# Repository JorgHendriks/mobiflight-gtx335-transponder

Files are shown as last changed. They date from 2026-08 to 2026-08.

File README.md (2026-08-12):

# GTX 335 Flight-Simulator Transponder

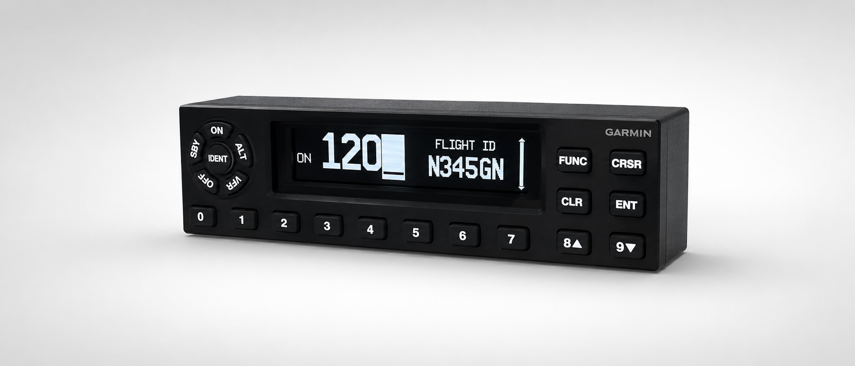
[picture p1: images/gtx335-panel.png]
GTX 335 flight-simulator transponder


A DIY desktop flight-simulator transponder inspired by the Garmin GTX 335 and designed for use with [MobiFlight](https://www.mobiflight.com/). The project combines a custom PCB, a 3D-printed and laser-engraved enclosure, and MobiFlight community firmware.

> [!IMPORTANT]
> This is an unofficial hobby project for flight simulation. It is not a real transponder, does not transmit ADS-B or radio signals, is not certified for aviation use, and is not affiliated with or endorsed by Garmin.

## Features

- Raspberry Pi Pico-based board with a 3.12-inch OLED and 20 illuminated buttons
- Most functions of the real GTX 335 are implemented, including transponder, altitude, and timer functions
- Preconfigured MobiFlight firmware and an example Microsoft Flight Simulator 2024 project

## Repository contents

| Folder | Contents |
|---|---|
| [`pcb`](pcb/README.md) | KiCad source, schematic, bill of materials, component notes, and ready-to-order fabrication archive |
| [`mechanical`](mechanical/README.md) | FreeCAD source, printable parts, laser artwork, print settings, and enclosure assembly notes |
| [`firmware`](firmware/README.md) | MobiFlight community firmware source and build instructions |
| [`firmware/MF_Configs`](firmware/MF_Configs) | Board configuration backup and an example MSFS 2024 MobiFlight project |

## What you need

- The components listed in the [PCB bill of materials](pcb/README.md#bill-of-materials)
- A manufactured and assembled PCB
- The hardware, printed enclosure parts and engraved controls described in the [enclosure guide](mechanical/README.md)
- A Windows PC running [MobiFlight](https://www.mobiflight.com/)
- Microsoft Flight Simulator 2024 if you want to use the included example project

## Quick start

### 1. Build the hardware

Order and assemble the board by following the [PCB guide](pcb/README.md), then print, engrave, and assemble the controls and enclosure by following the [mechanical guide](mechanical/README.md).

Pay particular attention to the OLED configuration and LED polarity of the switches.

### 2. Install the community firmware package

1. Download `GTX335_<version>.zip` from the [latest GitHub release](../../releases/latest).
2. Extract the archive into:

   ```text
   %LocalAppData%\MobiFlight\MobiFlight Connector\Community
   ```

   The resulting directory should be `Community\GTX335`.
3. Restart MobiFlight.
4. Connect the panel over USB and open **Extras > Settings > MobiFlight Modules**.
5. If necessary, reset the Pico from its board context menu. Then choose **Update firmware > Community > JH GTX335**.

The custom device and its twenty named buttons are stored in the firmware configuration, so a manual pin-by-pin setup is not normally required. For screenshots and more detail, see MobiFlight's [Community Board and Custom Devices user guide](https://github.com/MobiFlight/MobiFlight-Connector/wiki/User-guide-%E2%80%90-Community-Board-and-Custom-Devices).

If preferred, build a package from source by following the [firmware build instructions](firmware/README.md).

### 3. Load the MSFS 2024 example project

1. In MobiFlight 11 or newer, open [`firmware/MF_Configs/GTX335_MSFS2024.mfproj`](firmware/MF_Configs/GTX335_MSFS2024.mfproj), or merge its profile into an existing project.
2. If MobiFlight reports a missing controller, use **Extras > Controller Bindings** to bind the profile to the connected `JH GTX335`.
3. Start Microsoft Flight Simulator 2024, load an aircraft, and click **Run** in MobiFlight.

See the MobiFlight documentation for [opening and merging projects](https://docs.mobiflight.com/features/projects/) and [updating controller bindings](https://docs.mobiflight.com/features/controller-bindings/).

The included profile targets the generic MSFS 2024 transponder variables and events. Aircraft with custom avionics may need their own MobiFlight presets or calculator-code mappings.

## Current limitations

- Flight ID is display-only and cannot be entered from the panel.
- The SYS menu is only partially implemented.

## Building the firmware

Developer prerequisites, the PlatformIO command, generated files, and release-version handling are documented in [`firmware/README.md`](firmware/README.md).

## Licence

The firmware is available under the [MIT License](firmware/LICENSE). The PCB, 3D models, fabrication files, artwork, and project documentation are available for non-commercial use under [CC BY-NC-SA 4.0](LICENSE.md).

Third-party names and trademarks are not included in these licences. See the [complete licensing details](LICENSE.md).

## Contributing

Bug reports, tested aircraft mappings, firmware improvements, and fabrication feedback are welcome. When reporting a hardware problem, include the PCB revision, Pico and OLED variants, MobiFlight version, simulator and aircraft, and clear photos where relevant.

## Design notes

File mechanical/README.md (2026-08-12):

# Enclosure and controls

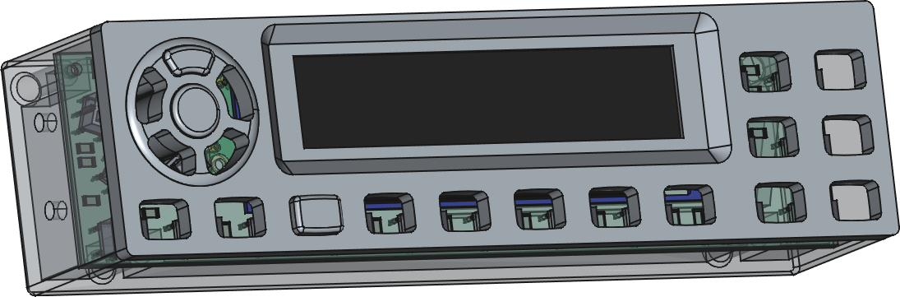
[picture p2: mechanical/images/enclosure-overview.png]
GTX 335 enclosure overview


## Hardware

- 4 × M2 x 15 mm + 3 mm Brass PCB standoff spacers
- 4 × M2 × 6 mm screws
- 4 x M3 x 8 mm screws
- Matte black paint

## 3D Printing

Use:

- White PLA for the buttons and faceplate
- Matte black PLA for the case

### Buttons

Print several spare buttons. They require little filament or paint, and achieving correct laser alignment may take more than one attempt.

Required quantities:

- `button_std`: print at least 2
- All other button models: print at least 1 each

Print the buttons with their top surfaces facing down on a smooth PEI build plate.

Recommended slicer settings:

| Setting | Value |
|---|---|
| Wall generator | Arachne |
| Initial layer flow ratio | 1.06 |
| Bottom surface pattern | Hilbert curve |
| Elephant foot compensation | 0.08 mm |

The Arachne wall generator is recommended because of the thin walls and small printed features.

### Faceplate

Recommended slicer settings:

| Setting | Value |
|---|---|
| Ironing | Enabled |
| Ironing flow | 23% |

## Laser Engraving

Use three separate laser sessions:

1. Faceplate
2. Standard buttons
3. Round and dome buttons

For each session:

1. Focus the laser on the top surface of the printed part.
2. Engrave the alignment outline onto the surface underneath.
3. Position the printed part inside the engraved outline.

Reference settings for a 10 W diode laser:

| Operation | Power | Speed | Focus |
|---|---:|---:|---|
| Standard raster engraving | 15% | 2800 mm/min | Focused |
| Button outline engraving | 50% | 2000 mm/min | Defocused |

## Assembly

Depending on the dimensional accuracy of your printer, the faceplate holes for the PCB standoff spacers may need to be prepared before final assembly.

Carefully form the threads using an M2 self-tapping screw before installing the PCB standoffs or final screws. Keep the screw perpendicular to the printed part and avoid overtightening.

## Mounting

The case includes two M4 side-mounting holes with 16 mm center-to-center spacing. The hole centers are positioned 12 mm from the rear of the case.

M4 side-mounting hole dimensions

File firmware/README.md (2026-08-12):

# GTX335 Firmware

This directory contains the configured MobiFlight community firmware for the GTX335 flight-simulator transponder. It targets the original RP2040-based Raspberry Pi Pico v1 and builds the `jh_gtx335` PlatformIO environment.

> **Disclaimer:** This firmware was created as an AI experiment, and its entire codebase was AI-generated; though it works, it does not meet the author's usual coding standards and should be reviewed accordingly.

End users normally install the precompiled community package from a GitHub release as described in the [project quick start](../README.md#quick-start). The instructions below are for developers building the firmware from source.

## Prerequisites

- [Git](https://git-scm.com/)
- [Visual Studio Code](https://code.visualstudio.com/) with the [PlatformIO IDE extension](https://platformio.org/install/ide?install=vscode), or the standalone [PlatformIO Core CLI](https://docs.platformio.org/en/latest/core/installation/index.html)
- Internet access for the first build

The first build downloads the pinned MobiFlight Firmware Source core and the required PlatformIO platforms and libraries. The downloaded `src`, `.pio`, `_build`, and `_dist` directories are generated locally and ignored by Git.

## Compile

Open the `firmware` directory—not the repository root—as the PlatformIO project. From a terminal in that directory, run:

```console
pio run -e jh_gtx335
```

In VS Code, the equivalent is **PlatformIO > Project Tasks > jh_gtx335 > General > Build**.

The build uses:

- MobiFlight Firmware Source core `3.0.0`
- Raspberry Pi Pico / RP2040 with the Arduino-Pico core
- U8g2 for the SSD1322 display

## Build artifacts

A successful local build with no explicit version produces:

```text
.pio/build/jh_gtx335/jh_gtx335_1_0_0.uf2
_dist/GTX335_1.0.0.zip
```

The UF2 file is the compiled firmware. The ZIP file is the complete MobiFlight community package and includes the board definition, custom-device definition, reset firmware, and compiled UF2 in the directory layout expected by MobiFlight.

The `_build` directory is an intermediate staging area.

## Set a build version

Set the `VERSION` environment variable before building to create versioned firmware and package filenames. In PowerShell:

```powershell
$env:VERSION = "1.0.0"
pio run -e jh_gtx335
```

On macOS or Linux:

```sh
VERSION=1.0.0 pio run -e jh_gtx335
```

GitHub release builds take the version from the release tag automatically. Prefer tags such as `v1.0.0`.

## Flash a development build

For normal use, install the generated community ZIP through MobiFlight as described in the [project quick start](../README.md#quick-start).

To flash the UF2 directly during development:

1. Disconnect the Pico.
2. Hold **BOOTSEL** while reconnecting its USB cable.
3. Release **BOOTSEL** when the `RPI-RP2` drive appears.
4. Copy the generated `.uf2` file to that drive.

The Pico restarts automatically after accepting the file. Direct UF2 flashing installs the firmware but does not install the board and device definitions into MobiFlight; use the generated community ZIP as well if MobiFlight has not already been configured for this board.

## Clean and rebuild

```console
pio run -e jh_gtx335 -t clean
pio run -e jh_gtx335
```

## Source layout

| Path | Purpose |
|---|---|
| `GTX335/GTX335State.*` | Panel state, key behavior, timers, message handling, and local settings |
| `GTX335/GTX335Renderer.*` | SSD1322 screen rendering and power/brightness control |
| `GTX335/GTX335Input.*` | Button polling, debouncing, long presses, and repeat behavior |
| `GTX335/GTX335Transport.*` | Named button events sent to MobiFlight |
| `GTX335/MFCustomDevice.*` | Integration with the MobiFlight custom-device API |
| `GTX335/Community` | Board, device, reset-firmware, and release-package metadata |
| `MF_Configs` | MobiFlight board backup and example MSFS 2024 project |

Hardware pin assignments are centralized in `GTX335/GTX335Pins.h`; the matching fixed MobiFlight configuration is in `GTX335/MFCustomDevicesConfig.h`.

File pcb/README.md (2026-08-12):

# PCB

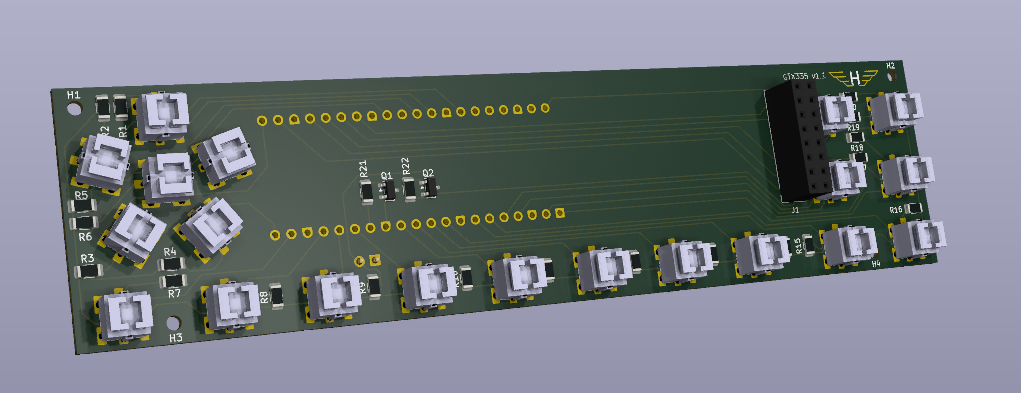
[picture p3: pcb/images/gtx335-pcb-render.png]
GTX335 PCB rendering


## PCB manufacturing

The fabrication files for the latest PCB are included in:

[Download the GTX335 v1.1 PCB fabrication files](./GTX335_v1_1_pcb_fab.zip)

Upload the ZIP archive directly to your PCB manufacturer and select a standard board thickness of **1.6 mm**.

## Schematic

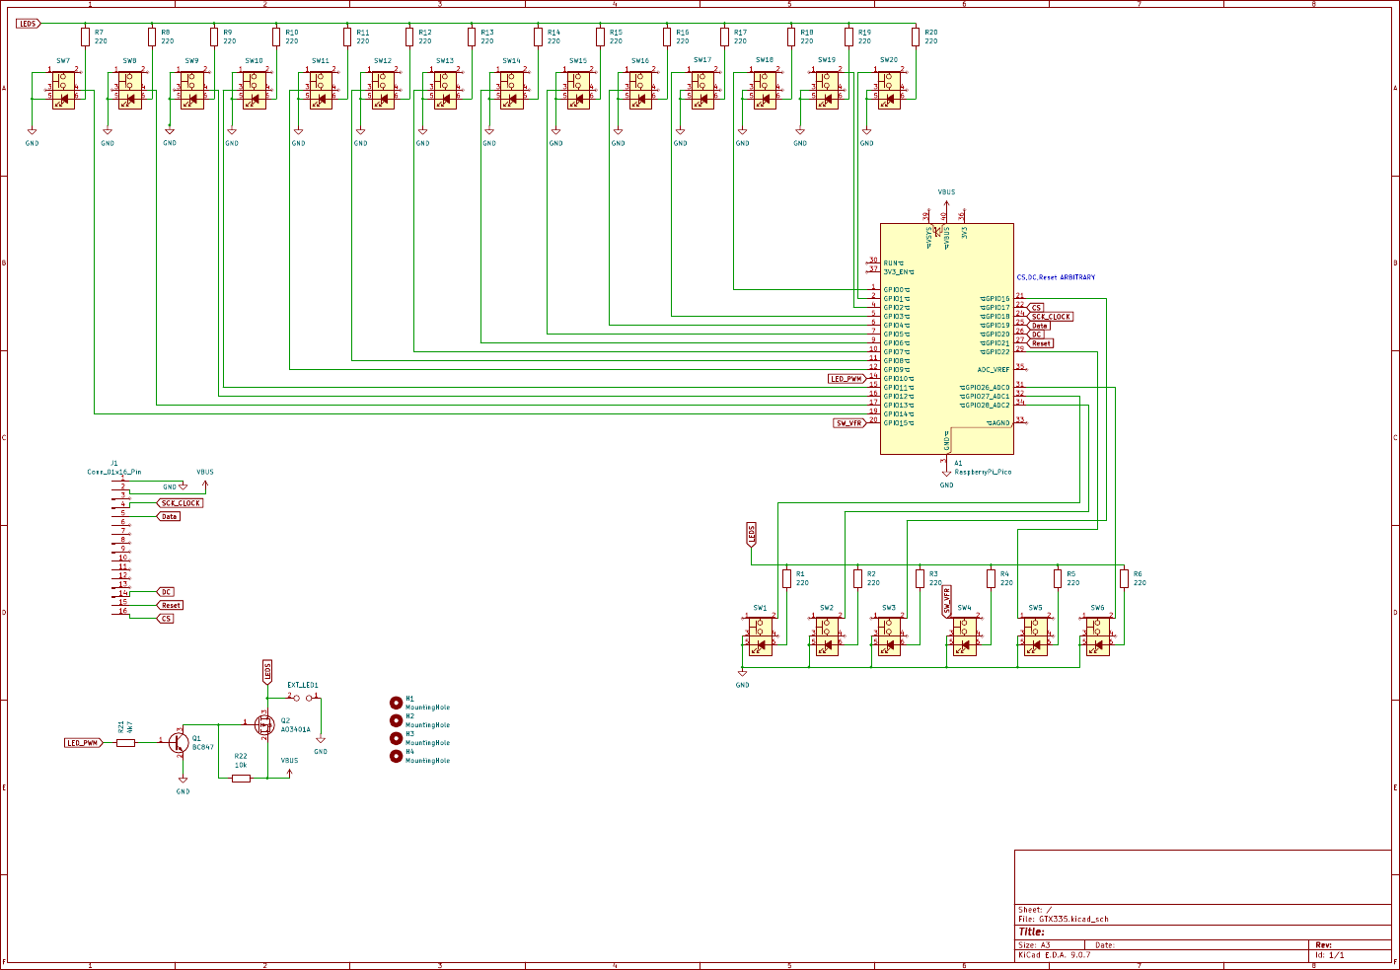
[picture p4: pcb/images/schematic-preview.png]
GTX335 PCB schematic


[View the full-resolution schematic](GTX335_Schematic.pdf)

## Bill of materials

| Designators | Quantity | Component | Specification |
|---|---:|---|---|
| SW1-SW20 | 20 | Illuminated tactile switch | 6 x 6 x 7.2 mm, six pins, white LED |
| R1-R20 | 20 | Resistor | 220 ohm, 1206 package |
| R21, R22 | 2 | Resistor | 10 kohm, 1206 package |
| Q1 | 1 | NPN transistor | BC847, SOT-23 package |
| Q2 | 1 | P-channel MOSFET | AO3401A, SOT-23 package |
| J1 | 1 | Socket header | 2 x 8 pins, 2.54 mm pitch, vertical |
| A1 | 2 | Female socket header | 20 pins, 2.54 mm pitch |
| - | 1 | Microcontroller board | Raspberry Pi Pico v1 |
| - | 1 | OLED display | 3.12-inch, 256 x 64 pixels, SSD1322 controller |

## Parts

### Illuminated tactile switches

Use twenty illuminated tactile switches with the following specifications:

- Body size: 6 x 6 mm
- Total height: 7.2 mm
- Number of pins: 6
- Integrated LED colour: white
- Switch contact: normally open

[6 x 6 x 7.2 mm illuminated tactile switch with white LED](https://nl.aliexpress.com/item/1005008121502218.html)

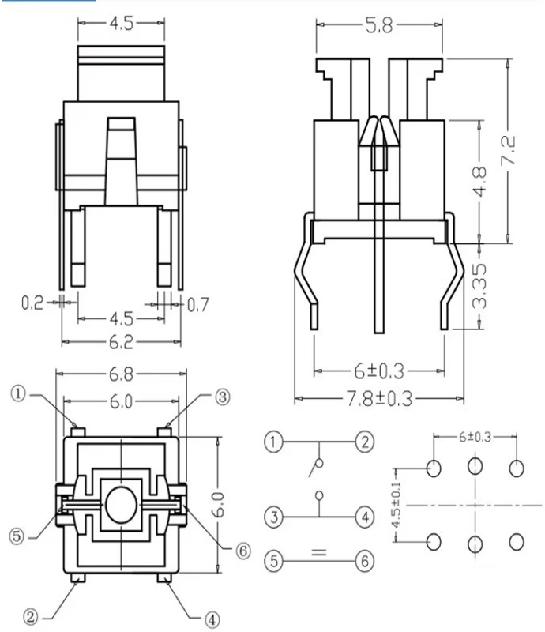
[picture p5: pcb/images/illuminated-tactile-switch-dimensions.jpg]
Illuminated tactile switch technical drawing


Four pins form the two duplicated switch contacts. The remaining two pins connect the integrated LED.

Verify the dimensions, height, and six-pin layout before ordering. Similar-looking 6 x 6 mm switches may use a different height, LED polarity, pin arrangement, or PCB footprint.

### OLED display

Use a 3.12-inch graphic OLED module with the following specifications:

- Resolution: 256 x 64 pixels
- Controller: SSD1322
- Interface: 4-wire SPI
- Connector: 16 pins
- Module width: approximately 100.5 mm
- Module height: approximately 33.5 mm

[SSD1322 3.12-inch 256 x 64 OLED display](https://nl.aliexpress.com/item/1005003091450549.html)

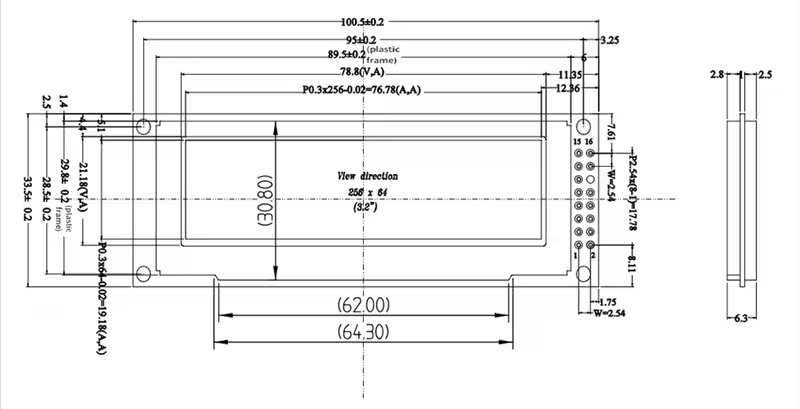
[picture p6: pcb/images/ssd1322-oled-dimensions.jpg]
SSD1322 OLED technical drawing


Check the specs carefully as some OLED screens are sold without the interface board or with different chipsets.

#### OLED pinout

| Pin | Symbol | Function | Use in 4-wire SPI mode |
|---:|---|---|---|
| 1 | VSS | Power-supply ground | Ground |
| 2 | VCC_IN | Positive power supply | Power |
| 3 | NC | Not connected | Not used |
| 4 | D0/CLK | Parallel data D0 / serial clock | SPI clock |
| 5 | D1/DIN | Parallel data D1 / serial data | SPI data |
| 6 | D2 | Parallel data D2 | Not used |
| 7 | D3 | Parallel data D3 | Not used |
| 8 | D4 | Parallel data D4 | Not used |
| 9 | D5 | Parallel data D5 | Not used |
| 10 | D6 | Parallel data D6 | Not used |
| 11 | D7 | Parallel data D7 | Not used |
| 12 | E/RD# | Enable / read | Not used after interface configuration |
| 13 | R/W# | Read / write | Not used after interface configuration |
| 14 | D/C# | Data / command selection | Data/command |
| 15 | RES# | Reset | Reset |
| 16 | CS# | Chip selection | Chip select |

### Raspberry Pi Pico

Use a **Raspberry Pi Pico v1** fitted with two 20-pin, 2.54 mm pitch headers.

The PCB is designed for the original RP2040-based Raspberry Pi Pico. Other Pico variants are not currently supported.

Install the Pico in the two corresponding 20-pin header rows on the PCB.

## Assembly notes

### Configure the OLED for 4-wire SPI

Before installing the OLED module, configure it for the **4-wire SPI interface**. This mode may be marked as **4SPI** on the display PCB.

Configure the interface-selection jumpers by soldering the required **0 ohm jumper resistors** according to the 4SPI configuration shown for the module.

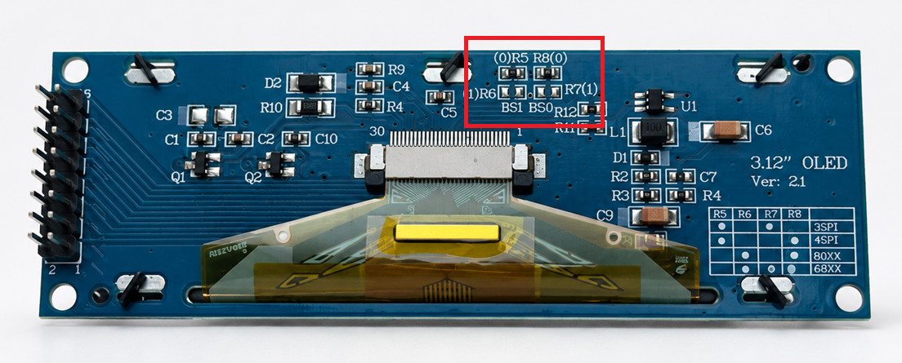
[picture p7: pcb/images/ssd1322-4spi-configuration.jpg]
OLED 4-wire SPI jumper configuration


### Install the illuminated tactile switches

Each tactile switch contains a polarity-sensitive LED.

The **small square PCB pad is ground** and must connect to the negative LED terminal (short).

To test the switch LEDs during assembly, apply 3–5 V DC to pin 2 of the EXT LED connector and connect the supply ground to any PCB ground point.

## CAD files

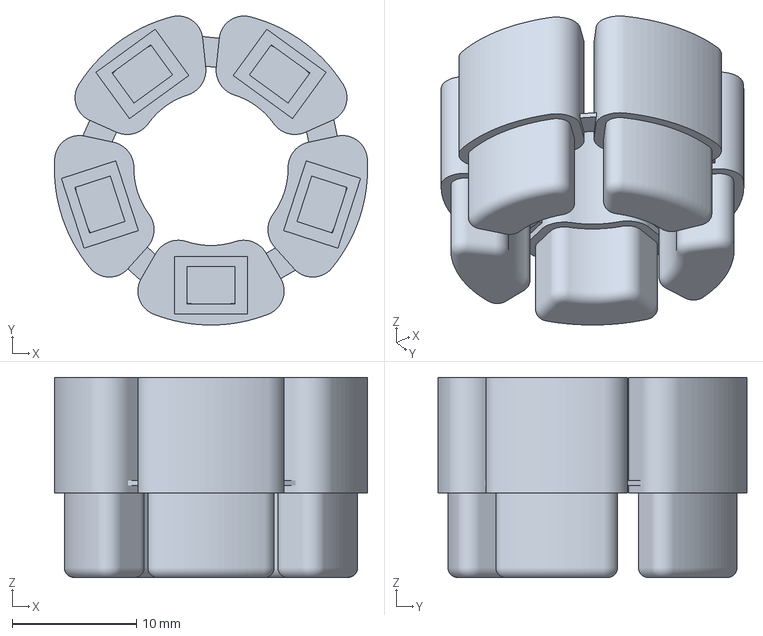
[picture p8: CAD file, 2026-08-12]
mechanical/Button_dome_print.3mf
25.2 x 24.9 x 16.1 mm

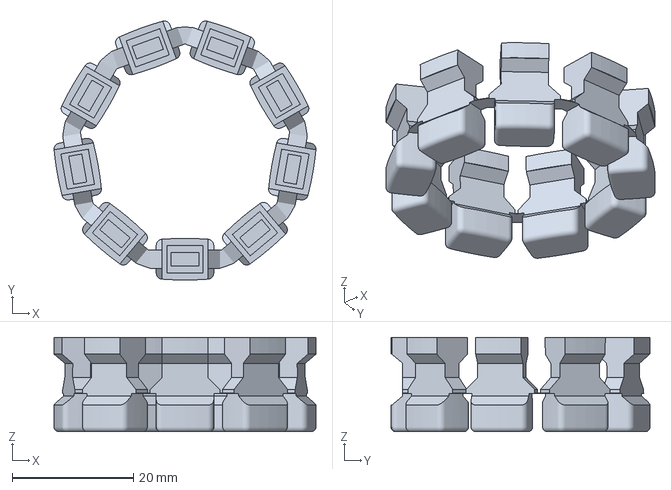
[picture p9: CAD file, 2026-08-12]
mechanical/Button_std_print.3mf
43.3 x 42.8 x 15.6 mm

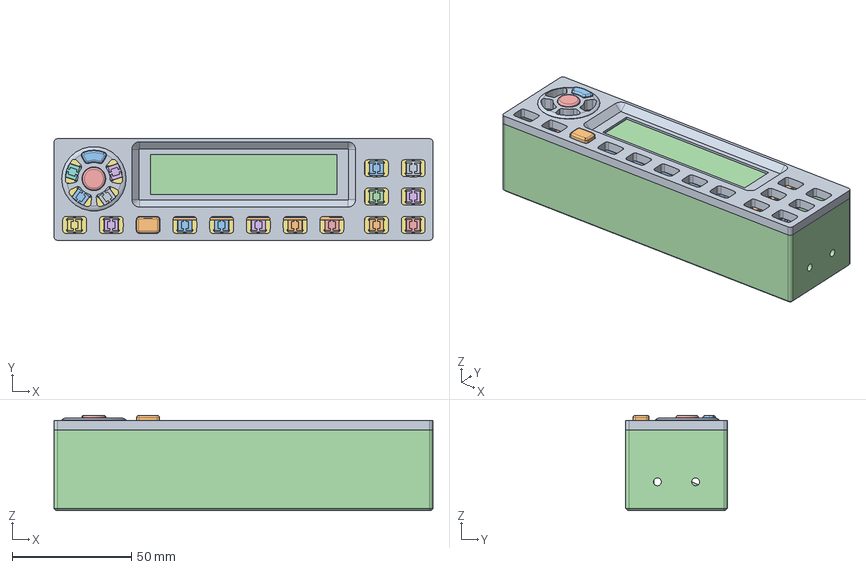
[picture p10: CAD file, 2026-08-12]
mechanical/GTX335.FCStd
158.8 x 42.6 x 39.8 mm
Faceplate
Button Standard
Button Dome
SW01 Switch Housing
SW01 Switch Base
SW02 Switch Housing
SW02 Switch Base
R01 1206 Resistor
R02 1206 Resistor
R03 1206 Resistor
SW03 Switch Housing
SW03 Switch Base
SW04 Switch Housing
SW04 Switch Base
R04 1206 Resistor
R05 1206 Resistor
SW05 Switch Housing
SW05 Switch Base
R06 1206 Resistor
R07 1206 Resistor
R08 1206 Resistor
SW06 Switch Housing
SW06 Switch Base
SW07 Switch Housing
SW07 Switch Base
SW08 Switch Housing
SW08 Switch Base
R09 1206 Resistor
R10 1206 Resistor
R11 1206 Resistor
SW09 Switch Housing
SW09 Switch Base
SW10 Switch Housing
SW10 Switch Base
SW11 Switch Housing
SW11 Switch Base
R12 1206 Resistor
SW12 Switch Housing
SW12 Switch Base
Q1 BC847
R13 1206 Resistor
R14 1206 Resistor
SW13 Switch Housing
SW13 Switch Base
2x08 Pin Socket
R15 1206 Resistor
SW14 Switch Housing
SW14 Switch Base
SW15 Switch Housing
SW15 Switch Base
R16 1206 Resistor
R17 1206 Resistor
Q2 AO3401A
SW16 Switch Housing
SW16 Switch Base
R18 1206 Resistor
R19 1206 Resistor
SW17 Switch Housing
SW17 Switch Base
R20 1206 Resistor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

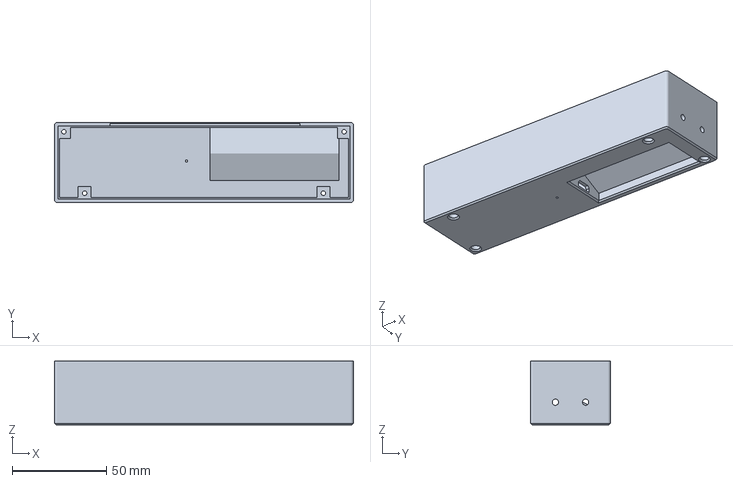
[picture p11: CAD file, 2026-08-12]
mechanical/GTX335_case.3mf
158.8 x 42.6 x 33.8 mm

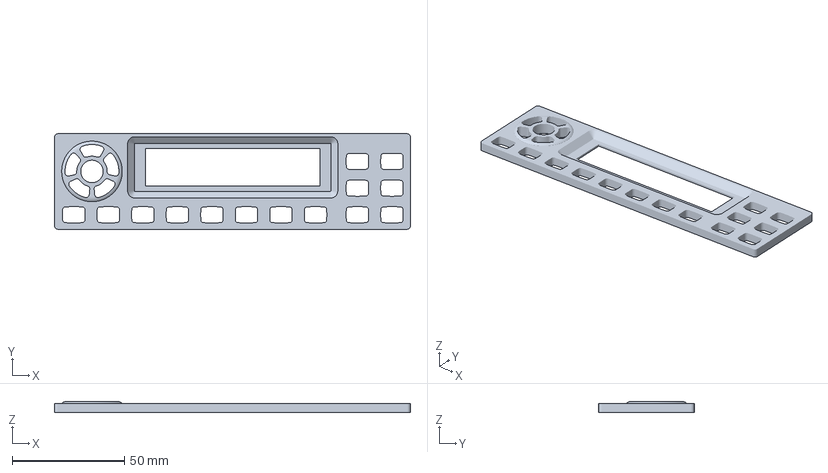
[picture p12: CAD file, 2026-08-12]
mechanical/GTX335_faceplate.3mf
158.8 x 42.6 x 5.00 mm

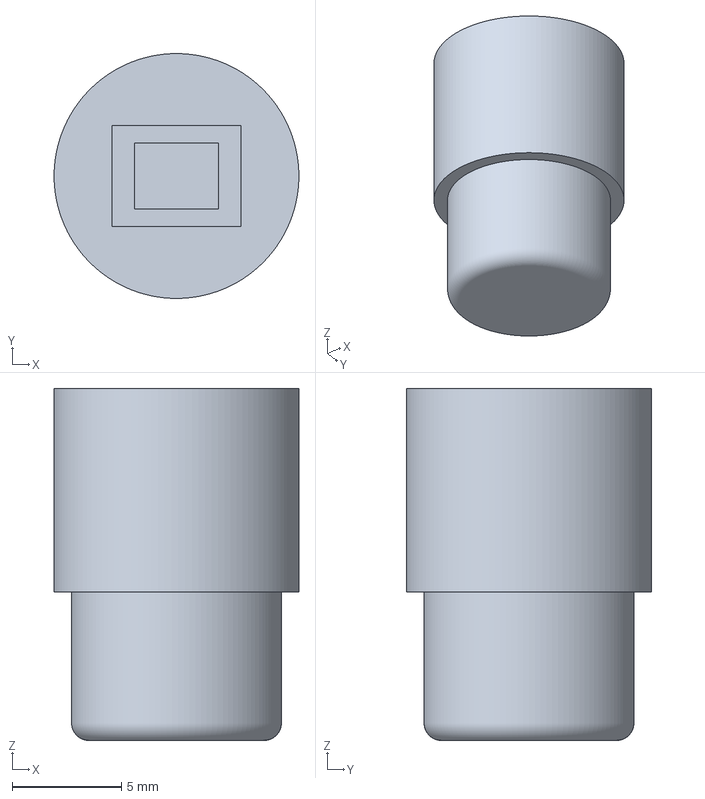
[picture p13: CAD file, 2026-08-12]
mechanical/Button_round.3mf
11.2 x 11.2 x 16.1 mm

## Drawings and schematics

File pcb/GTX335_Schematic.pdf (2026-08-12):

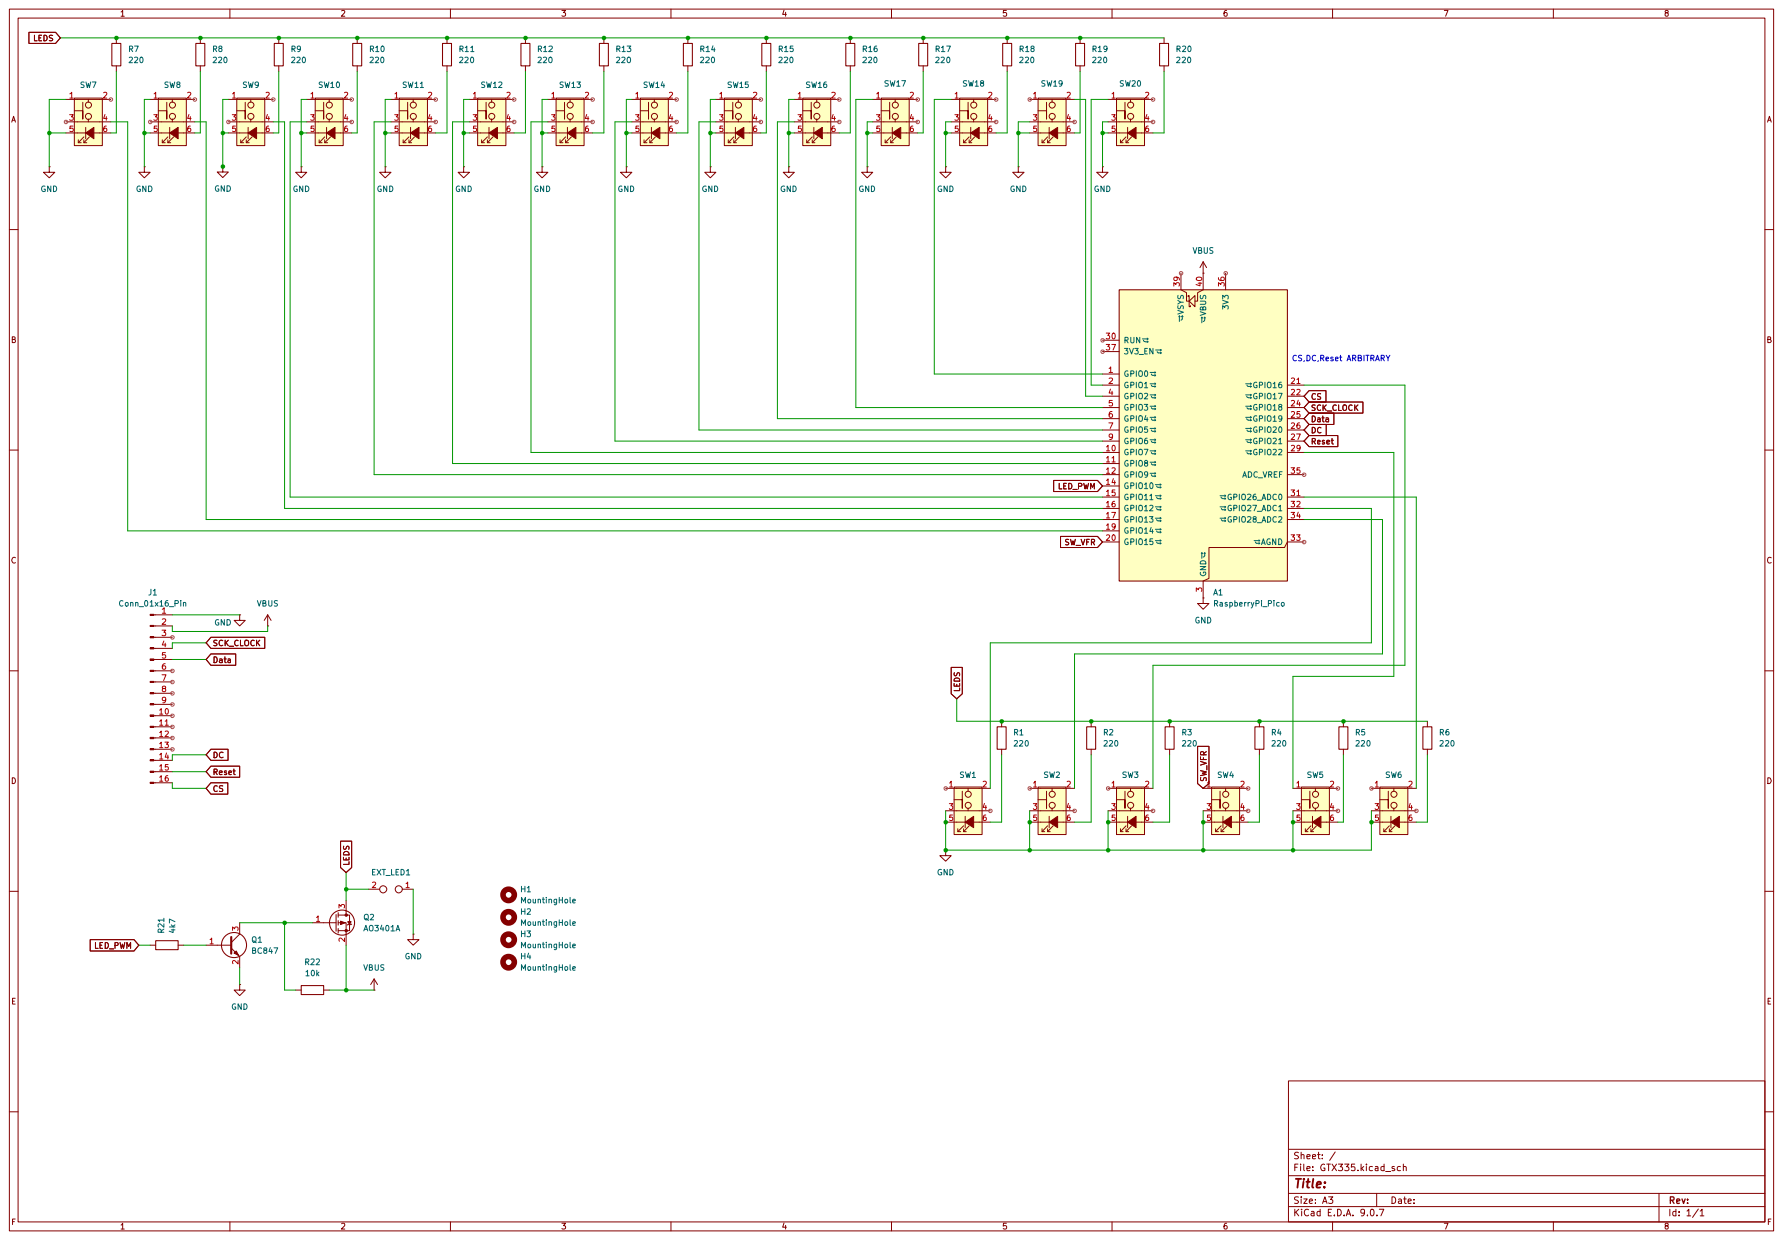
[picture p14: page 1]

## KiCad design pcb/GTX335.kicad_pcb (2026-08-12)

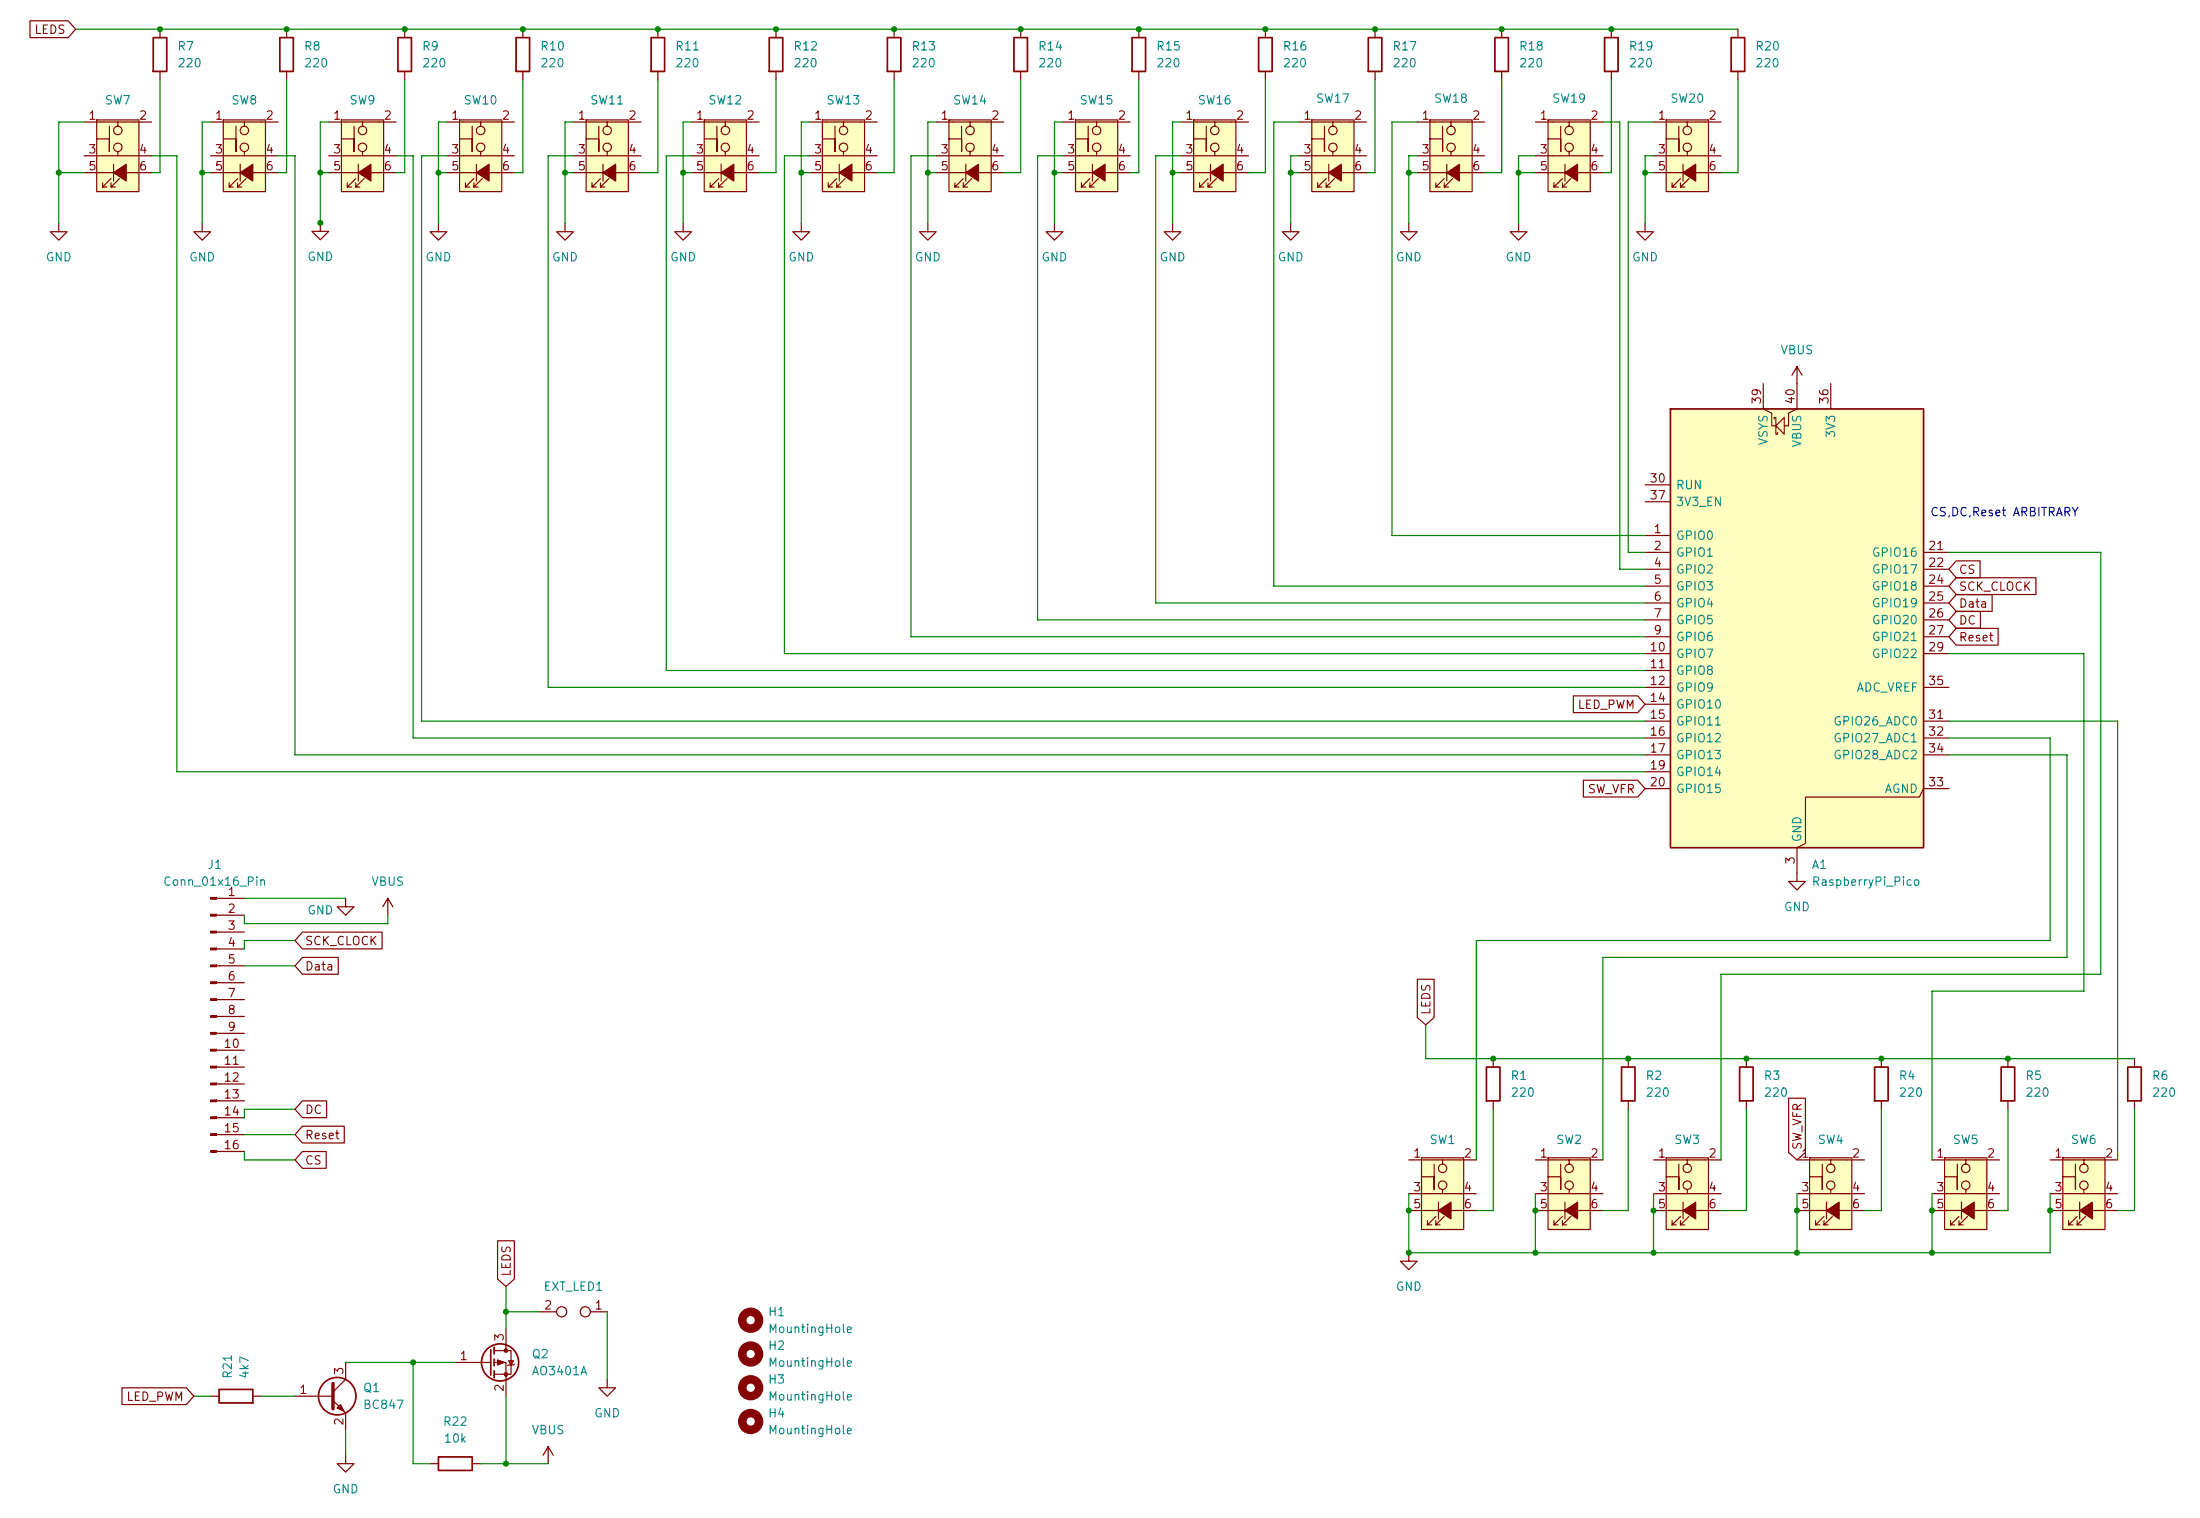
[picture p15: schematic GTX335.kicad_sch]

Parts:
A1: RaspberryPi_Pico; RaspberryPi_Pico_Common_Unspecified
EXT_LED1: TestPoint_2Pole; PinHeader_2x01_P2.54mm_Vertical
H1, H2, H3, H4: MountingHole; MountingHole_2.2mm_M2
J1: Conn_01x16_Pin; PinSocket_2x08_P2.54mm_Vertical
Q1: BC847; SOT-23
Q2: AO3401A; SOT-23
R1, R2, R3, R4, R5, R6, R7, R8, R9, R10, R11, R12, R13, R14, R15, R16, R17, R18, R19, R20: 220; R_1206_3216Metric
R21: 4k7; R_1206_3216Metric
R22: 10k; R_1206_3216Metric
SW1, SW2, SW3, SW4, SW5, SW6, SW7, SW8, SW9, SW10, SW11, SW12, SW13, SW14, SW15, SW16, SW17, SW18, SW19, SW20: SW_Push_LED_6p; SW_PUSH_LED_6mm_H7.2mm

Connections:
CS: A1.22 (GPIO17), J1.16
DC: A1.26 (GPIO20), J1.14
Data: A1.25 (GPIO19), J1.5
GND: A1.3 (GND), A1.8 (GND), A1.13 (GND), A1.18 (GND), A1.23 (GND), A1.28 (GND), A1.38 (GND), EXT_LED1.1, J1.1, Q1.2 (E), SW1.3, SW1.5 (K), SW2.3, SW2.5 (K), SW3.3, SW3.5 (K), SW4.3, SW4.5 (K), SW5.3, SW5.5 (K), SW6.3, SW6.5 (K), SW7.1, SW7.5 (K), SW8.1, SW8.5 (K), SW9.1, SW9.5 (K), SW10.1, SW10.5 (K), SW11.1, SW11.5 (K), SW12.1, SW12.5 (K), SW13.1, SW13.5 (K), SW14.1, SW14.5 (K), SW15.1, SW15.5 (K), SW16.1, SW16.5 (K), SW17.3, SW17.5 (K), SW18.3, SW18.5 (K), SW19.3, SW19.5 (K), SW20.3, SW20.5 (K)
LEDS: EXT_LED1.2, Q2.3 (D), R1.1, R2.1, R3.1, R4.1, R5.1, R6.1, R7.1, R8.1, R9.1, R10.1, R11.1, R12.1, R13.1, R14.1, R15.1, R16.1, R17.1, R18.1, R19.1, R20.1
LED_PWM: A1.14 (GPIO10), R21.1
unnamed: A1.1 (GPIO0), SW18.1
unnamed: A1.2 (GPIO1), SW20.1
unnamed: A1.4 (GPIO2), SW19.2
unnamed: A1.5 (GPIO3), SW17.1
unnamed: A1.6 (GPIO4), SW16.3
unnamed: A1.7 (GPIO5), SW15.3
unnamed: A1.9 (GPIO6), SW14.3
unnamed: A1.10 (GPIO7), SW13.3
unnamed: A1.11 (GPIO8), SW12.3
unnamed: A1.12 (GPIO9), SW11.3
unnamed: A1.15 (GPIO11), SW10.3
unnamed: A1.16 (GPIO12), SW9.4
unnamed: A1.17 (GPIO13), SW8.4
unnamed: A1.19 (GPIO14), SW7.4
unnamed: A1.21 (GPIO16), SW3.2
unnamed: A1.29 (GPIO22), SW5.1
unnamed: A1.31 (GPIO26_ADC0), SW6.2
unnamed: A1.32 (GPIO27_ADC1), SW1.2
unnamed: A1.34 (GPIO28_ADC2), SW2.2
unnamed: Q1.1 (B), R21.2
unnamed: Q1.3 (C), Q2.1 (G), R22.2
unnamed: R1.2, SW1.6
unnamed: R2.2, SW2.6
unnamed: R3.2, SW3.6
unnamed: R4.2, SW4.6
unnamed: R5.2, SW5.6
unnamed: R6.2, SW6.6
unnamed: R7.2, SW7.6
unnamed: R8.2, SW8.6
unnamed: R9.2, SW9.6
unnamed: R10.2, SW10.6
unnamed: R11.2, SW11.6
unnamed: R12.2, SW12.6
unnamed: R13.2, SW13.6
unnamed: R14.2, SW14.6
unnamed: R15.2, SW15.6
unnamed: R16.2, SW16.6
unnamed: R17.2, SW17.6
unnamed: R18.2, SW18.6
unnamed: R19.2, SW19.6
unnamed: R20.2, SW20.6
Reset: A1.27 (GPIO21), J1.15
SCK_CLOCK: A1.24 (GPIO18), J1.4
SW_VFR: A1.20 (GPIO15), SW4.1
VBUS: A1.40 (VBUS), J1.2, Q2.2 (S), R22.1

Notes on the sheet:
CS,DC,Reset ARBITRARY

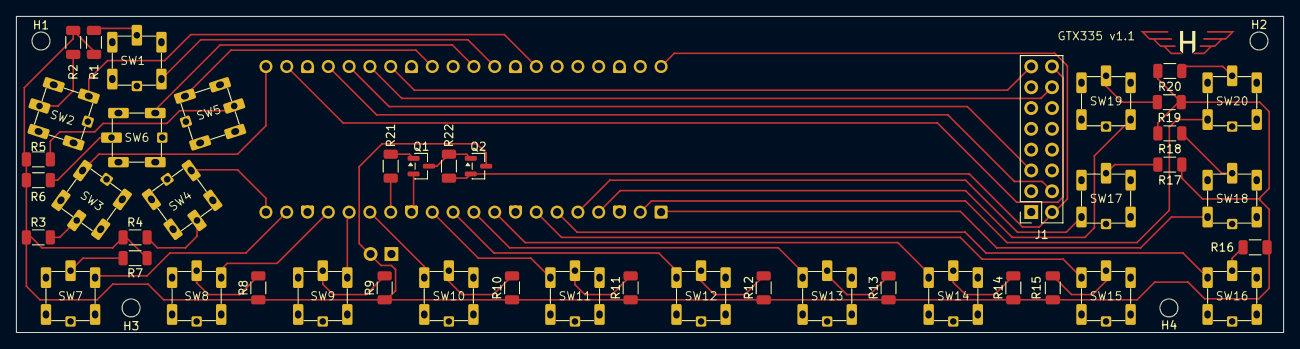
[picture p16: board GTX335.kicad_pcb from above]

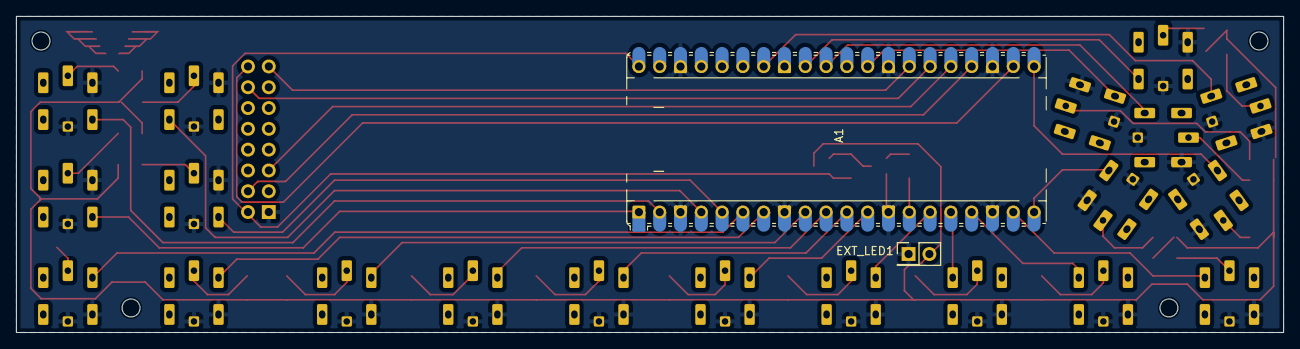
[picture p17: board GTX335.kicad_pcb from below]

Board: 2 copper layers, 154.8 x 38.6 mm, 51 parts (2 on the bottom side), 51 nets.

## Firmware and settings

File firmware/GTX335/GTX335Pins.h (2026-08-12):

#pragma once

#include <Arduino.h>

#include "GTX335State.h"

namespace gtx335::pins
{
constexpr uint8_t OledCs = 17;
constexpr uint8_t OledSck = 18;
constexpr uint8_t OledMosi = 19;
constexpr uint8_t OledDc = 20;
constexpr uint8_t OledReset = 21;
constexpr uint8_t Backlight = 10;

constexpr uint8_t DefaultButtons[ButtonCount] = {
    14, 13, 12, 11, 9, 8, 7, 6, 5, 4, 27, 28, 16, 15, 22, 26, 2, 1, 3, 0};
}

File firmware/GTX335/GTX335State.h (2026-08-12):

#pragma once

#include <Arduino.h>

namespace gtx335
{
constexpr uint8_t ButtonCount = 20;
constexpr uint32_t LogoDurationMs = 2500;
constexpr uint32_t SelfTestDurationMs = 3000;
constexpr uint32_t FunctionLabelDurationMs = 1000;
constexpr uint32_t AltitudeWarningDurationMs = 2000;
constexpr int32_t AltitudeMonitorThresholdFeet = 250;
constexpr uint32_t DefaultDownCounterSeconds = 60U * 60U;

enum class Key : uint8_t {
    Digit0,
    Digit1,
    Digit2,
    Digit3,
    Digit4,
    Digit5,
    Digit6,
    Digit7,
    Digit8,
    Digit9,
    On,
    Standby,
    Off,
    Vfr,
    Alt,
    Ident,
    Function,
    Cursor,
    Clear,
    Enter,
};

enum class Mode : uint8_t { Off, On, Standby, Alt };
enum class Function : uint8_t { Xpdr, Timer, Altitude, System };
enum class StartupPhase : uint8_t { Logo, SelfTest, Normal };
enum class SystemSelection : uint8_t { None, Value, Offset };

struct CounterState {
    uint32_t seconds = 0;
    bool running = false;
};

struct SquawkEditor {
    bool active = false;
    uint8_t count = 0;
    char digits[5] = {'\0', '\0', '\0', '\0', '\0'};
};

struct DownCounterEditor {
    bool active = false;
    uint32_t originalSeconds = DefaultDownCounterSeconds;
    uint8_t digitCount = 0;
    char digits[7] = {'\0', '\0', '\0', '\0', '\0', '\0', '\0'};
};

struct DeviceState {
    Mode mode = Mode::Alt;
    Function function = Function::Xpdr;
    StartupPhase startupPhase = StartupPhase::Logo;
    uint32_t phaseStartedMs = 0;
    uint32_t functionLabelUntilMs = 0;

    bool suspended = false;
    bool connectorStopped = false;
    bool dirty = true;

    char squawk[5] = {'0', '0', '0', '0', '\0'};
    char flightId[9] = {'-', '-', '-', '-', '-', '-', '\0', '\0', '\0'};
    SquawkEditor squawkEditor;

    bool pressureAltitudeValid = false;
    int32_t pressureAltitudeFeet = 0;
    bool staticAirTemperatureValid = false;
    int32_t staticAirTemperatureCelsius = 0;
    bool densityAltitudeValid = false;
    int32_t densityAltitudeFeet = 0;
    bool replyVisible = false;

    bool simOnGround = true;
    CounterState upCounter;
    CounterState downCounter = {DefaultDownCounterSeconds, false};
    CounterState flightTimer;
    CounterState tripTimer;
    uint32_t lastTimerTickMs = 0;
    DownCounterEditor downCounterEditor;

    bool altitudeMonitorArmed = false;
    int32_t altitudeMonitorReferenceFeet = 0;
    bool altitudeMonitorOutside = false;
    uint32_t altitudeWarningUntilMs = 0;
    bool offButtonPressed = false;

    uint8_t pageByFunction[4] = {0, 0, 0, 0};
    SystemSelection systemSelection = SystemSelection::None;

    int8_t backlightBasePercent = 25;
    int8_t backlightOffsetPercent = 0;
    int8_t contrastBasePercent = 25;
    int8_t contrastOffsetPercent = 0;
};

void initializeState(DeviceState &state, uint32_t nowMs);
void tickState(DeviceState &state, uint32_t nowMs);
void applyMessage(DeviceState &state, int16_t messageId, const char *value);

bool isDownCounterPage(const DeviceState &state);
bool isDownCounterEditing(const DeviceState &state);
bool shouldSuppressPress(const DeviceState &state, Key key);

void wakeSuspended(DeviceState &state);
void handleKeyPress(DeviceState &state, Key key, uint32_t nowMs);
void handleKeyRelease(DeviceState &state, Key key, bool longPressHandled, uint32_t nowMs);
void handleKeyLongPress(DeviceState &state, Key key, uint32_t nowMs);
void handleKeyRepeat(DeviceState &state, Key key, uint32_t nowMs);

uint8_t currentPage(const DeviceState &state);
uint8_t pageCount(Function function);
int8_t effectiveBacklightPercent(const DeviceState &state);
int8_t effectiveContrastPercent(const DeviceState &state);

const char *modeLabel(Mode mode);
const char *functionLabel(Function function);

}
